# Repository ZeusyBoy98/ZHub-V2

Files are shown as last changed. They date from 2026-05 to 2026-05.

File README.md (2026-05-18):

# ZHub-V2
A complex USB 3.2 Hub to suite my needs.
Made for Hack Club Fallout

## Zine
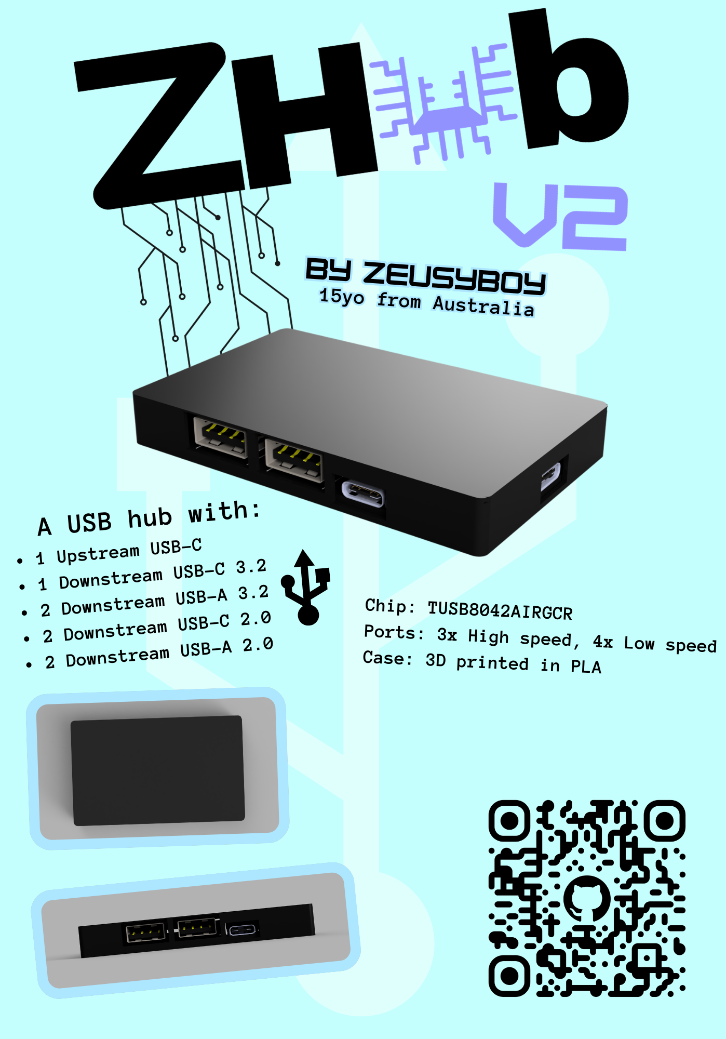
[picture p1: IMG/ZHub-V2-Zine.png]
Zine


## What?
A basic USB hub with:
<ul>
<li> 1 Upstream USB-C
<li> 1 Downstream USB-C 3.2
<li> 2 Downstream USB-A 3.2
<li> 2 Downstream USB-C 2.0
<li> 2 Downstream USB-A 2.0
<li> USB 2.0 because I used a very basic chip
</ul>

## Why?
Because I don't have any USB-C USB hubs and A to C adapters are annoying. If I can just have one good USB hub on me at all times, that can allow me to plug all the stuff I could possibly need in, then that achieves my goal.

## How?
In order to make this project for yourself, you'll need to purchase the board and get it assembled through PCBA with all the components below (PCB manufacturer-acceptable BOM at PCB/Gerbers/bom.csv). You'll also have to 3D print the case.
| Quantity | Item | URL | Unit Price ($USD) | Total Price ($USD) |
| --- | --- | --- | --- | --- |
| 5 | CoreChips SL2.1A | https://www.lcsc.com/product-detail/C192893.html  | 0.2522 | 1.26 |
| 10 | USB A 2.0 Receptacle | https://www.lcsc.com/product-detail/C668591.html  | 0.0667 | 0.67 |
| 20 | USB C 2.0 Receptacle | https://www.lcsc.com/product-detail/C2765186.html | 0.0666 | 1.33 |
| 100 | 1uf Capacitor | https://www.lcsc.com/product-detail/C107372.html  | 0.0019 | 0.19 |
| 100 | 100nf Capacitor | https://www.lcsc.com/product-detail/C309458.html  | 0.0012 | 0.12 |
| 100 | 5.1k Resistor | https://www.lcsc.com/product-detail/C2906874.html | 0.0006 | 0.06 |
| 5 | TUSB8042A | https://www.lcsc.com/product-detail/C2860610.html | 8.1684 | 40.84 |
| 10 | USB A 3.1 Receptacle | https://www.lcsc.com/product-detail/C309458.html  | 0.23 | 2.3 |
| 5 | USB C 3.2 Receptacle | https://www.lcsc.com/product-detail/C134092.html  | 1.0565 | 5.28 |
| 20 | ESD Diode | https://www.lcsc.com/product-detail/C82044.html | 0.0359 | 0.72 |
| 10 | 24Mhz Crystal | https://www.lcsc.com/product-detail/C5444545.html | 0.0615 | 0.62 |
| 10 | Polyfuse | https://www.lcsc.com/product-detail/C883135.html  | 0.0616 | 0.62 |
| 10 | 22uf Capacitor | https://www.lcsc.com/product-detail/C105226.html  | 0.0455 | 0.46 |
| 100 | 18pf Capacitor | https://www.lcsc.com/product-detail/C106202.html  | 0.0012 | 0.12 |
| 100 | 10uf Capacitor | https://www.lcsc.com/product-detail/C315248.html  | 0.0092 | 0.92 |
| 10 | 9.53k Resistor | https://www.lcsc.com/product-detail/C6127312.html | 0.0682 | 0.68 |
| 100 | 4.7k Resistor | https://www.lcsc.com/product-detail/C105871.html  | 0.0008 | 0.08 |
| 100 | 43k Resistor | https://www.lcsc.com/product-detail/C185415.html  | 0.001 | 0.10 |
| 100 | 1M Resistor | https://www.lcsc.com/product-detail/C138033.html  | 0.0009 | 0.09 |
| 5 | 220@100MHz Ferrite Bead | https://www.lcsc.com/product-detail/C454099.html  | 0.151 | 0.76 |
| 5 | 3.3V Buck Converter | https://www.lcsc.com/product-detail/C780769.html  | 0.4705 | 2.35 |
| PCB | | | 5.2 | 5.2 |
| PCBA | | | 145.82 | 145.82 |
| Shipping | | | | 10.51 |
| Total | | | | 161.53 |

### Build Guide:

#### 1. Preparation<br>
Before starting, make sure you have:
<ul>
<li>The gerbers, pick and place file, and BOM, all available in this repository at (PCB/production)
<li>A 3D printer (or get the printed parts from someone else)
</ul>

#### 2. Ordering
Go to your PCB manufacturer of choice (Make sure they have PCBA) and follow their instructions on how to order.

#### 3. Case
3D print the print file, CAD/ZHub-V2-Print.3mf <br>
This has all the case parts you need (top and bottom)

#### 4. Assembly
Once the case has finished printing, place the assembled PCB into said case, then get the lid and slide it into the grooves of the bottom half of the case to close it.

#### 5. Profit
Plug a USB-C to C cable into the upstream port of the hub (the one not next to any other ports), and plug the other end of that cable into your computer. Then plug whatever USB devices into the downstream ports and...

This project does not need firmware, so you're good to go!

Enjoy your ZHub!!!

## Renders
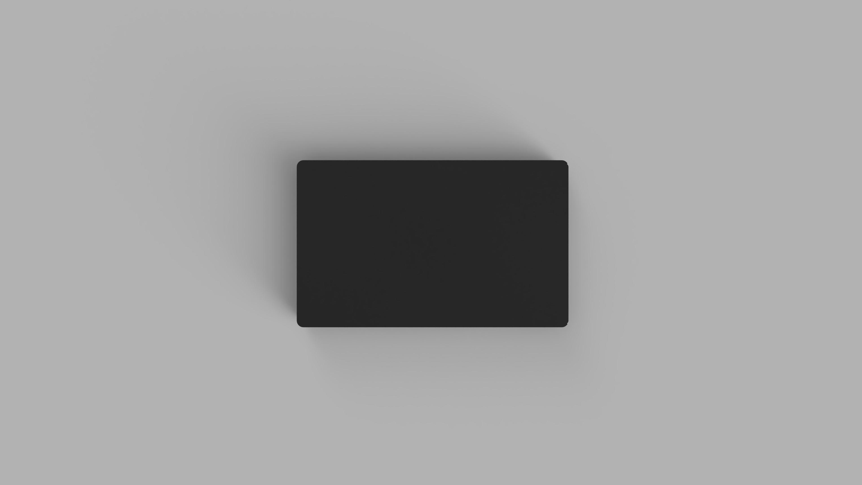
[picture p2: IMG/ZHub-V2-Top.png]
Top

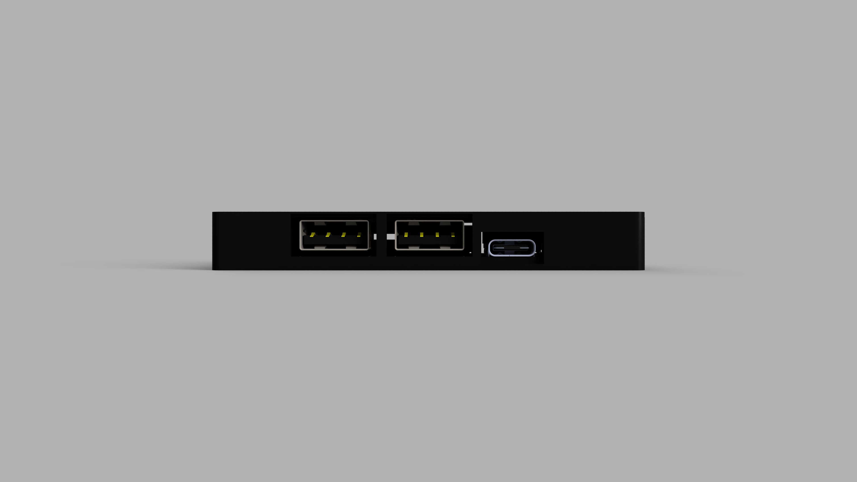
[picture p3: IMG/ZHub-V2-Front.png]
Front

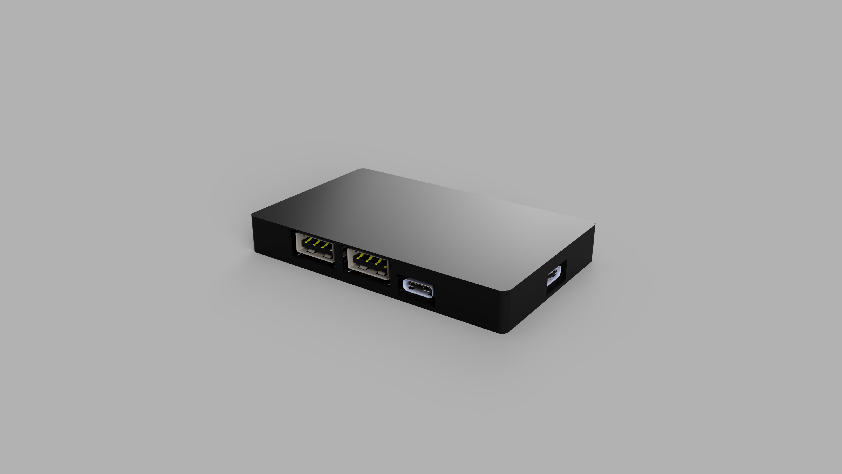
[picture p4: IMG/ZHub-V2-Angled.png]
Angled


## Designing
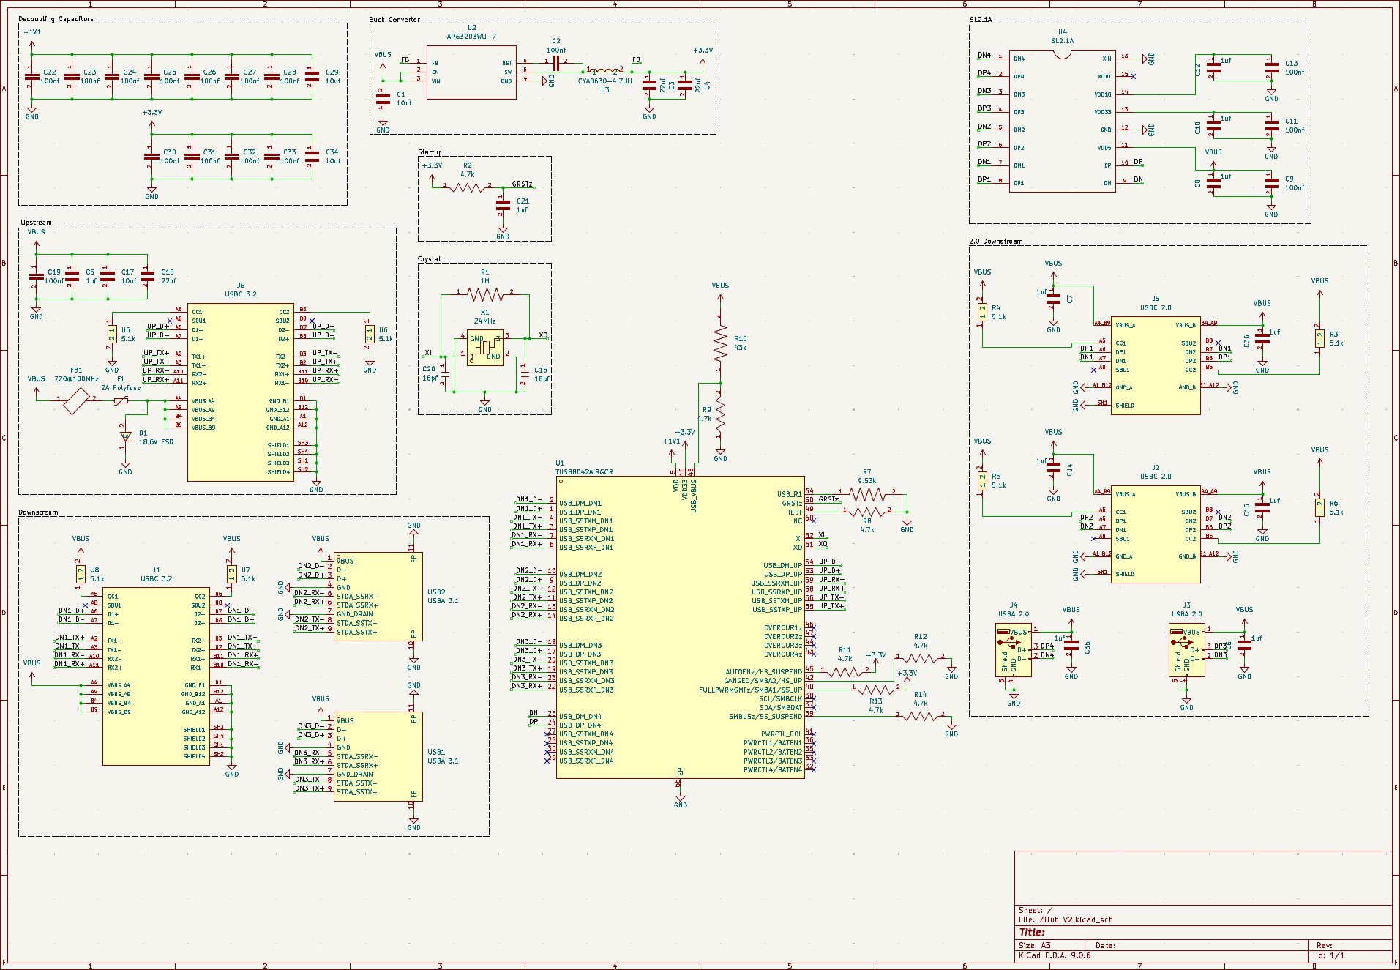
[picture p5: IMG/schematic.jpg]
Schematic

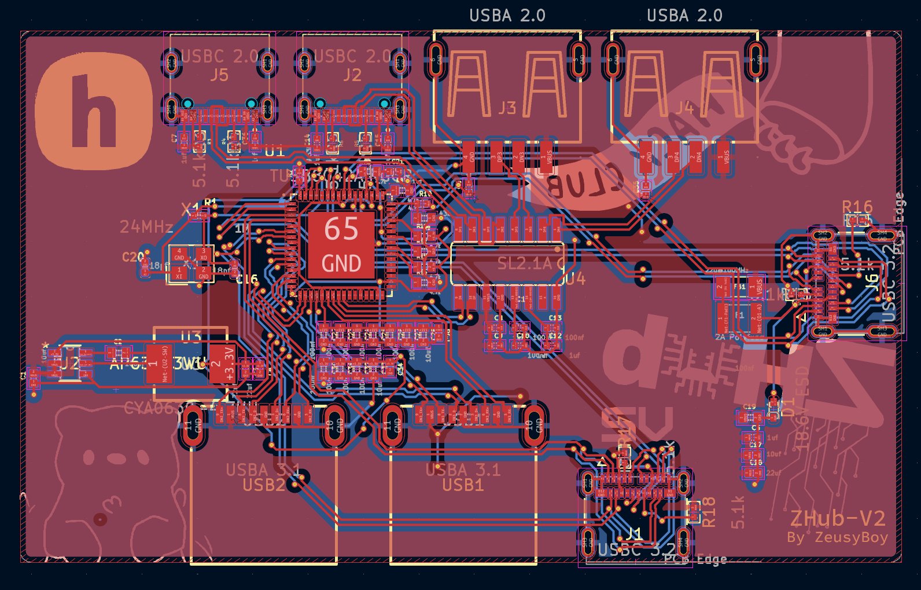
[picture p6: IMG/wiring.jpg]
Wiring

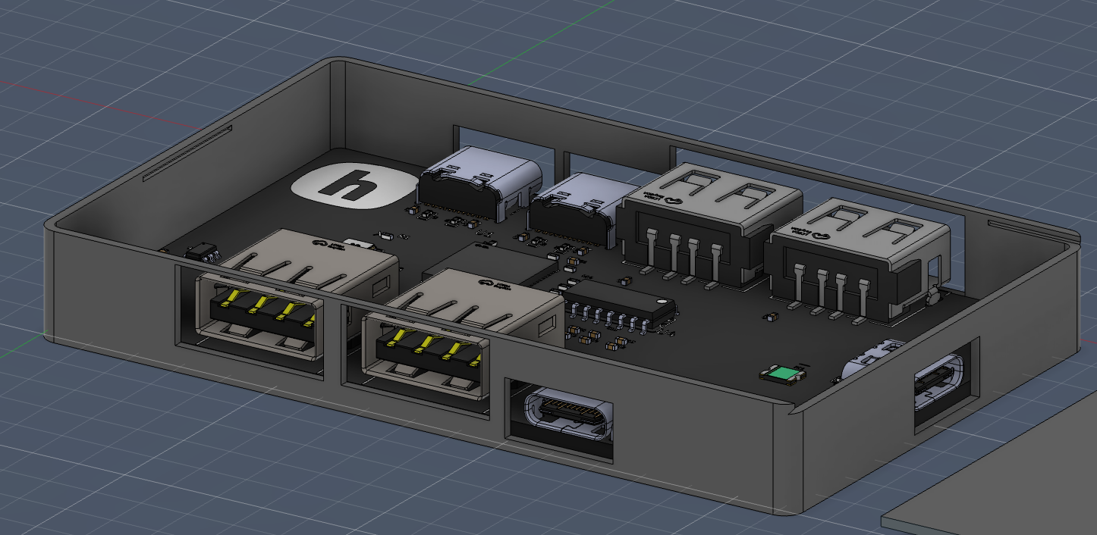
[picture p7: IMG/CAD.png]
CAD


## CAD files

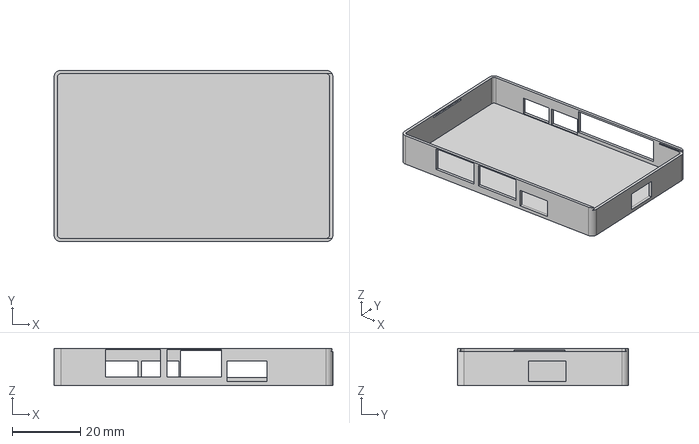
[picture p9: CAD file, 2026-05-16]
CAD/Parts/ZHub-V2-Bottom.stp
82.0 x 50.4 x 11.0 mm

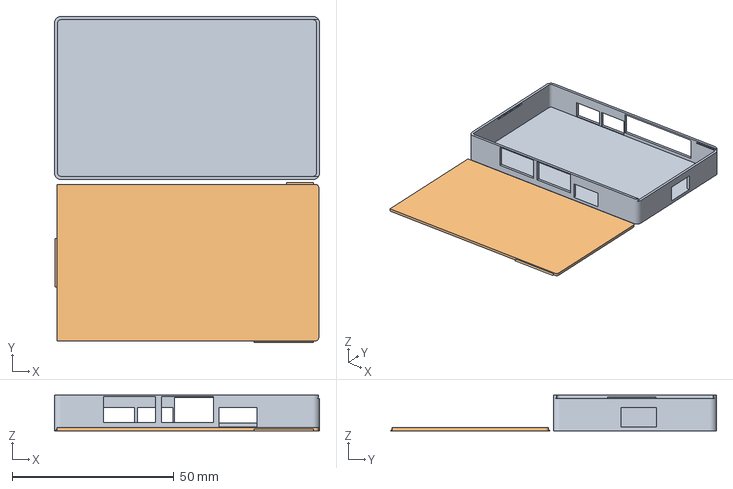
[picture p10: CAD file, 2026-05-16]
CAD/ZHub-V2-Print.3mf
82.0 x 100.8 x 11.0 mm
ZHub-V2-Bottom.stp
ZHub-V2-Top.stp

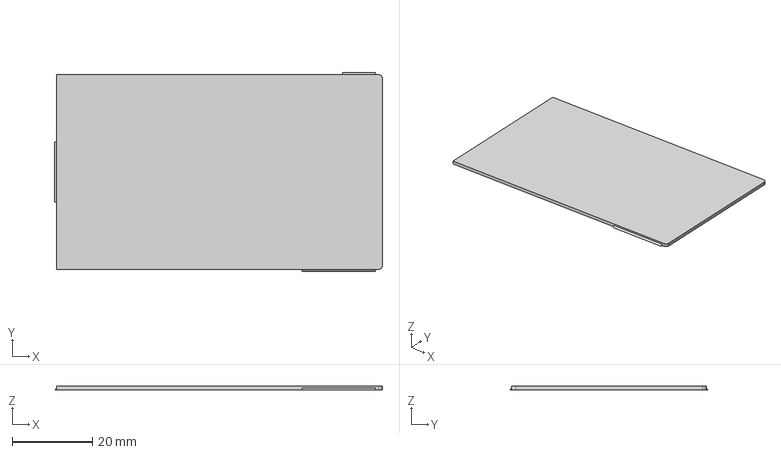
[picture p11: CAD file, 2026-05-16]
CAD/Parts/ZHub-V2-Top.stp
81.5 x 49.4 x 1.00 mm

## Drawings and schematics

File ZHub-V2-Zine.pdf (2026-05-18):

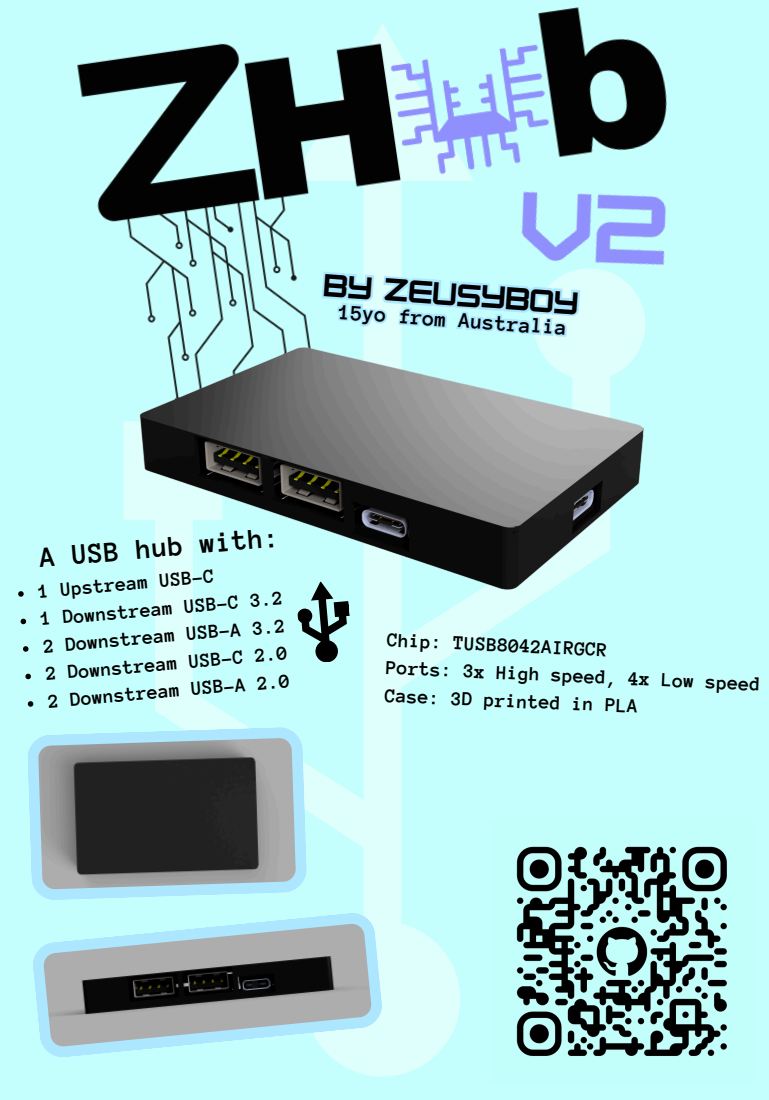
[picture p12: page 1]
1 Upstream USB-C 1 Downstream USB-C 3.2 2 Downstream USB-A 3.2 2 Downstream USB-C 2.0 2 Downstream USB-A 2.0; 15yo from Australia 1; usyBoy; Chip: TUSB8042AIRGCR

By ZeusyBoy By ZeusyBoy B

om Australia 15yo from Australia

A USB hub with:

Ports: 3x High speed, 4x Low speed

Case: 3D printed in PLA

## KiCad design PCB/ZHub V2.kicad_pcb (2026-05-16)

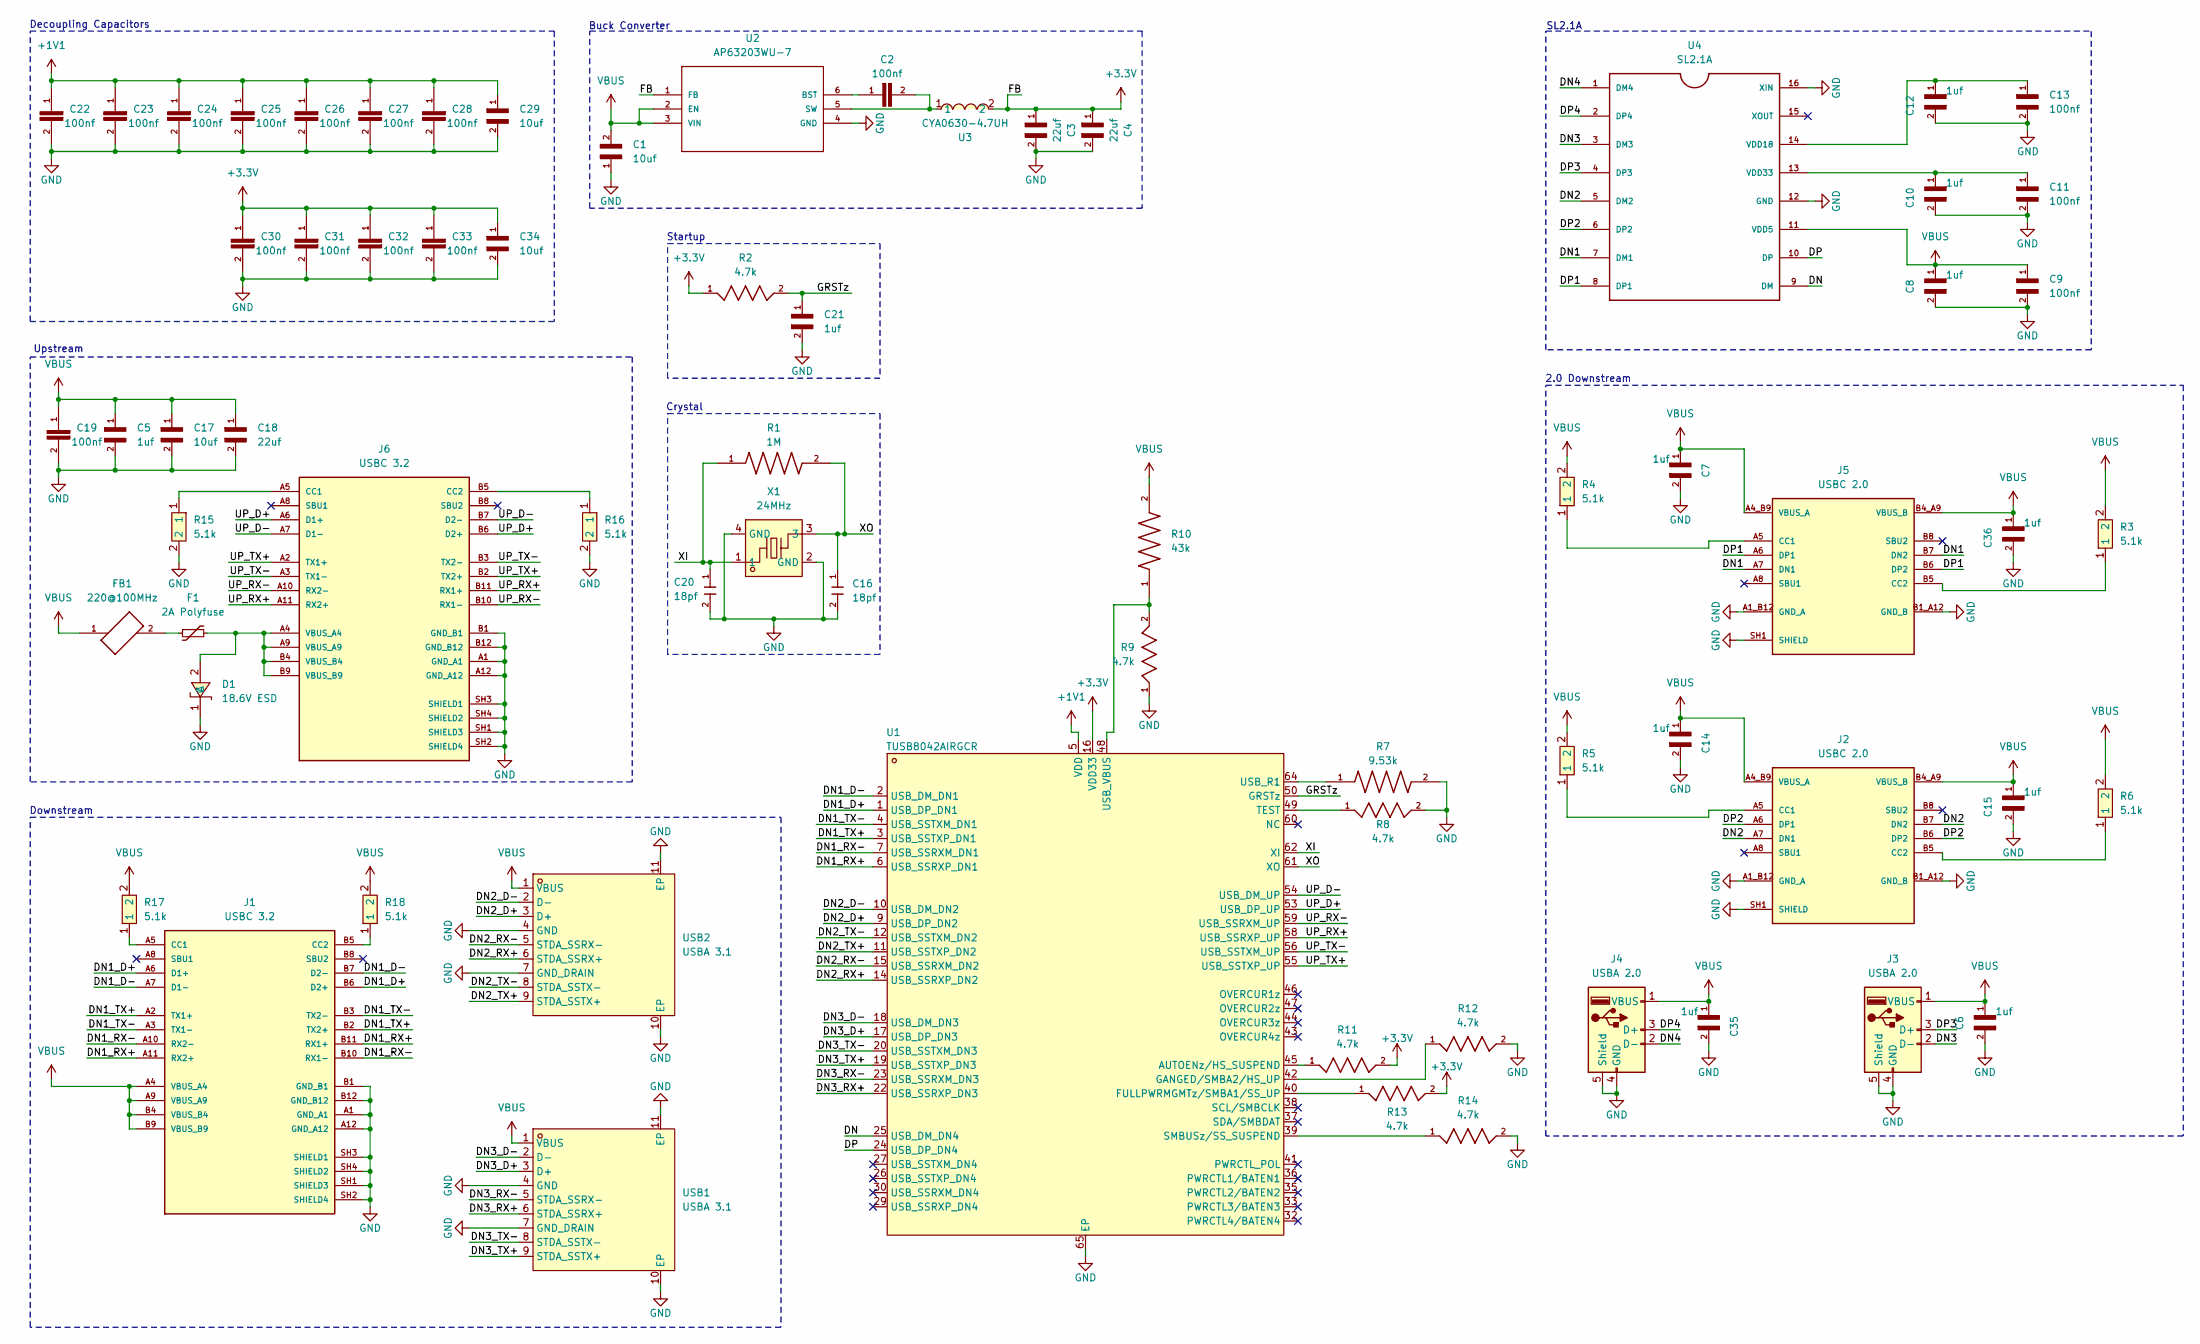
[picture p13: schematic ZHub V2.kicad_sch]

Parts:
C1, C17, C29, C34: 10uf; 10uf_10V_0402
C2, C19, C22, C23, C24, C25, C26, C27, C28, C30, C31, C32, C33: 100nf; 100nf_10V_0402
C3, C4, C18: 22uf; 22uf_6.3V_0402
C5, C21: 1uf; 1uf_6.3V_0402
C6, C7, C8, C10, C12, C14, C15, C35, C36: 1uf; 1uf_0402
C9, C11, C13: 100nf; 100nf_0402; DigiKey_Part_Number 399-C1210V104KCRACTUCT-ND
C16, C20: 18pf; 18pf_15V_0402; MPN CC0402JRNPO9BN180
D1: 18.6V ESD; SOD-523F_L1.2-W0.8-LS1.7-RD; LCSC Part C82044
F1: 2A Polyfuse; 1210
FB1: 220@100MHz; 220_100MHz_bead
J1, J6: USBC 3.2; MOLEX_3.2_TYPEC; PARTREV A7
J2, J5: USBC 2.0; SHOUHAN_TYPE-C_16PIN_2MD__073_; PARTREV A
J3, J4: USBA 2.0; USB-A-TH_10.0QHHTZB6.3
R1: 1M; 1M_50V_0402; PARTREV Nov-2024
R2, R8, R9, R11, R12, R13, R14: 4.7k; 4.7k_50V_0402
R3, R4, R5, R6: 5.1k; R0402; PARTREV 3/1/2020; LCSC Part C2906874
R7: 9.53k; 9.53k_0402; PARTREV V6
R10: 43k; 43k_50V_0402; DigiKey_Part_Number 311-43.0KLRCT-ND
R15, R16, R17, R18: 5.1k; R0402; LCSC Part C2906874
U1: TUSB8042AIRGCR; VQFN-64_L9.0-W9.0-P0.50-TL-EP6.0; LCSC Part C2860610
U2: AP63203WU-7; 3.3V_buck; MPN AP63203WU-7
U3: CYA0630-4.7UH; 5A_4.7uH_Inductor; LCSC Part C5189748
U4: SL2.1A; SLA2.1s
USB1, USB2: USBA 3.1; USB-A-SMD_U-A-39WD-W-1; LCSC Part C3020886
X1: 24MHz; CRYSTAL-SMD_4P-L3.2-W2.5-BL; LCSC Part C5444545

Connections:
+1V1: C22.1, C23.1, C24.1, C25.1, C26.1, C27.1, C28.1, C29.1, U1.5 (VDD), U1.8 (VDD), U1.13 (VDD), U1.21 (VDD), U1.28 (VDD), U1.31 (VDD), U1.51 (VDD), U1.57 (VDD)
+3.3V: C3.1, C4.1, C30.1, C31.1, C32.1, C33.1, C34.1, R2.1, R11.2, R13.2, U1.16 (VDD33), U1.34 (VDD33), U1.52 (VDD33), U1.63 (VDD33), U2.1 (FB), U3.2
/DN: U1.25 (USB_DM_DN4), U4.9 (DM)
/DN1: J5.A7 (DN1), J5.B7 (DN2), U4.7 (DM1)
/DN1_D+: J1.A6 (D1+), J1.B6 (D2+), U1.1 (USB_DP_DN1)
/DN1_D-: J1.A7 (D1-), J1.B7 (D2-), U1.2 (USB_DM_DN1)
/DN1_RX+: J1.A11 (RX2+), J1.B11 (RX1+), U1.6 (USB_SSRXP_DN1)
/DN1_RX-: J1.A10 (RX2-), J1.B10 (RX1-), U1.7 (USB_SSRXM_DN1)
/DN1_TX+: J1.A2 (TX1+), J1.B2 (TX2+), U1.3 (USB_SSTXP_DN1)
/DN1_TX-: J1.A3 (TX1-), J1.B3 (TX2-), U1.4 (USB_SSTXM_DN1)
/DN2: J2.A7 (DN1), J2.B7 (DN2), U4.5 (DM2)
/DN2_D+: U1.9 (USB_DP_DN2), USB2.3 (D+)
/DN2_D-: U1.10 (USB_DM_DN2), USB2.2 (D-)
/DN2_RX+: U1.14 (USB_SSRXP_DN2), USB2.6 (STDA_SSRX+)
/DN2_RX-: U1.15 (USB_SSRXM_DN2), USB2.5 (STDA_SSRX-)
/DN2_TX+: U1.11 (USB_SSTXP_DN2), USB2.9 (STDA_SSTX+)
/DN2_TX-: U1.12 (USB_SSTXM_DN2), USB2.8 (STDA_SSTX-)
/DN3: J3.2 (D-), U4.3 (DM3)
/DN3_D+: U1.17 (USB_DP_DN3), USB1.3 (D+)
/DN3_D-: U1.18 (USB_DM_DN3), USB1.2 (D-)
/DN3_RX+: U1.22 (USB_SSRXP_DN3), USB1.6 (STDA_SSRX+)
/DN3_RX-: U1.23 (USB_SSRXM_DN3), USB1.5 (STDA_SSRX-)
/DN3_TX+: U1.19 (USB_SSTXP_DN3), USB1.9 (STDA_SSTX+)
/DN3_TX-: U1.20 (USB_SSTXM_DN3), USB1.8 (STDA_SSTX-)
/DN4: J4.2 (D-), U4.1 (DM4)
/DP: U1.24 (USB_DP_DN4), U4.10 (DP)
/DP1: J5.A6 (DP1), J5.B6 (DP2), U4.8 (DP1)
/DP2: J2.A6 (DP1), J2.B6 (DP2), U4.6 (DP2)
/DP3: J3.3 (D+), U4.4 (DP3)
/DP4: J4.3 (D+), U4.2 (DP4)
/GRSTz: C21.1, R2.2, U1.50 (GRSTz)
/UP_D+: J6.A6 (D1+), J6.B6 (D2+), U1.53 (USB_DP_UP)
/UP_D-: J6.A7 (D1-), J6.B7 (D2-), U1.54 (USB_DM_UP)
/UP_RX+: J6.A11 (RX2+), J6.B11 (RX1+), U1.58 (USB_SSRXP_UP)
/UP_RX-: J6.A10 (RX2-), J6.B10 (RX1-), U1.59 (USB_SSRXM_UP)
/UP_TX+: J6.A2 (TX1+), J6.B2 (TX2+), U1.55 (USB_SSTXP_UP)
/UP_TX-: J6.A3 (TX1-), J6.B3 (TX2-), U1.56 (USB_SSTXM_UP)
/XI: C20.1, R1.1, U1.62 (XI), X1.1
/XO: C16.1, R1.2, U1.61 (XO), X1.3
GND: C1.1, C3.2, C4.2, C5.2, C6.2, C7.2, C8.2, C9.2, C10.2, C11.2, C12.2, C13.2, C14.2, C15.2, C16.2, C17.2, C18.2, C19.2, C20.2, C21.2, C22.2, C23.2, C24.2, C25.2, C26.2, C27.2, C28.2, C29.2, C30.2, C31.2, C32.2, C33.2, C34.2, C35.2, C36.2, D1.1 (C), J1.A1 (GND_A1), J1.A12 (GND_A12), J1.B1 (GND_B1), J1.B12 (GND_B12), J1.SH1 (SHIELD3), J1.SH2 (SHIELD4), J1.SH3 (SHIELD1), J1.SH4 (SHIELD2), J2.A1_B12 (GND_A), J2.B1_A12 (GND_B), J2.SH1 (SHIELD), J2.SH2 (SHIELD), J2.SH3 (SHIELD), J2.SH4 (SHIELD), J3.4 (GND), J3.5 (Shield), J3.6, J4.4 (GND), J4.5 (Shield), J4.6, J5.A1_B12 (GND_A), J5.B1_A12 (GND_B), J5.SH1 (SHIELD), J5.SH2 (SHIELD), J5.SH3 (SHIELD), J5.SH4 (SHIELD), J6.A1 (GND_A1), J6.A12 (GND_A12), J6.B1 (GND_B1), J6.B12 (GND_B12), J6.SH1 (SHIELD3), J6.SH2 (SHIELD4), J6.SH3 (SHIELD1), J6.SH4 (SHIELD2), R7.2, R8.2, R9.1, R12.2, R14.2, R15.2, R16.2, U1.65 (EP), U2.4 (GND), U4.12 (GND), U4.16 (XIN), USB1.4 (GND), USB1.7 (GND_DRAIN), USB1.10 (EP), USB1.11 (EP), USB2.4 (GND), USB2.7 (GND_DRAIN), USB2.10 (EP), USB2.11 (EP), X1.2 (GND), X1.4 (GND)
unnamed: D1.2 (A), F1.2, J6.A4 (VBUS_A4), J6.A9 (VBUS_A9), J6.B4 (VBUS_B4), J6.B9 (VBUS_B9)
unnamed: F1.1, FB1.2
unnamed: J1.A5 (CC1), R17.1
unnamed: J1.B5 (CC2), R18.1
unnamed: J2.A5 (CC1), R5.1
unnamed: J2.B5 (CC2), R6.1
unnamed: J5.A5 (CC1), R4.1
unnamed: J5.B5 (CC2), R3.1
unnamed: J6.A5 (CC1), R15.1
unnamed: J6.B5 (CC2), R16.1
unnamed: R11.1, U1.45 (AUTOENz/HS_SUSPEND)
unnamed: R13.1, U1.40 (FULLPWRMGMTz/SMBA1/SS_UP)
unnamed: R12.1, U1.42 (GANGED/SMBA2/HS_UP)
unnamed: R14.1, U1.39 (SMBUSz/SS_SUSPEND)
unnamed: R8.1, U1.49 (TEST)
unnamed: R7.1, U1.64 (USB_R1)
unnamed: R9.2, R10.1, U1.48 (USB_VBUS)
unnamed: C2.1, U2.6 (BST)
unnamed: C2.2, U2.5 (SW), U3.1
unnamed: C12.1, C13.1, U4.14 (VDD18)
unnamed: C10.1, C11.1, U4.13 (VDD33)
VBUS: C1.2, C5.1, C6.1, C7.1, C8.1, C9.1, C14.1, C15.1, C17.1, C18.1, C19.1, C35.1, C36.1, FB1.1, J1.A4 (VBUS_A4), J1.A9 (VBUS_A9), J1.B4 (VBUS_B4), J1.B9 (VBUS_B9), J2.A4_B9 (VBUS_A), J2.B4_A9 (VBUS_B), J3.1 (VBUS), J4.1 (VBUS), J5.A4_B9 (VBUS_A), J5.B4_A9 (VBUS_B), R3.2, R4.2, R5.2, R6.2, R10.2, R17.2, R18.2, U2.2 (EN), U2.3 (VIN), U4.11 (VDD5), USB1.1 (VBUS), USB2.1 (VBUS)

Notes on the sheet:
2.0 Downstream
Startup
Buck Converter
Downstream
Upstream
SL2.1A
Crystal
Decoupling Capacitors

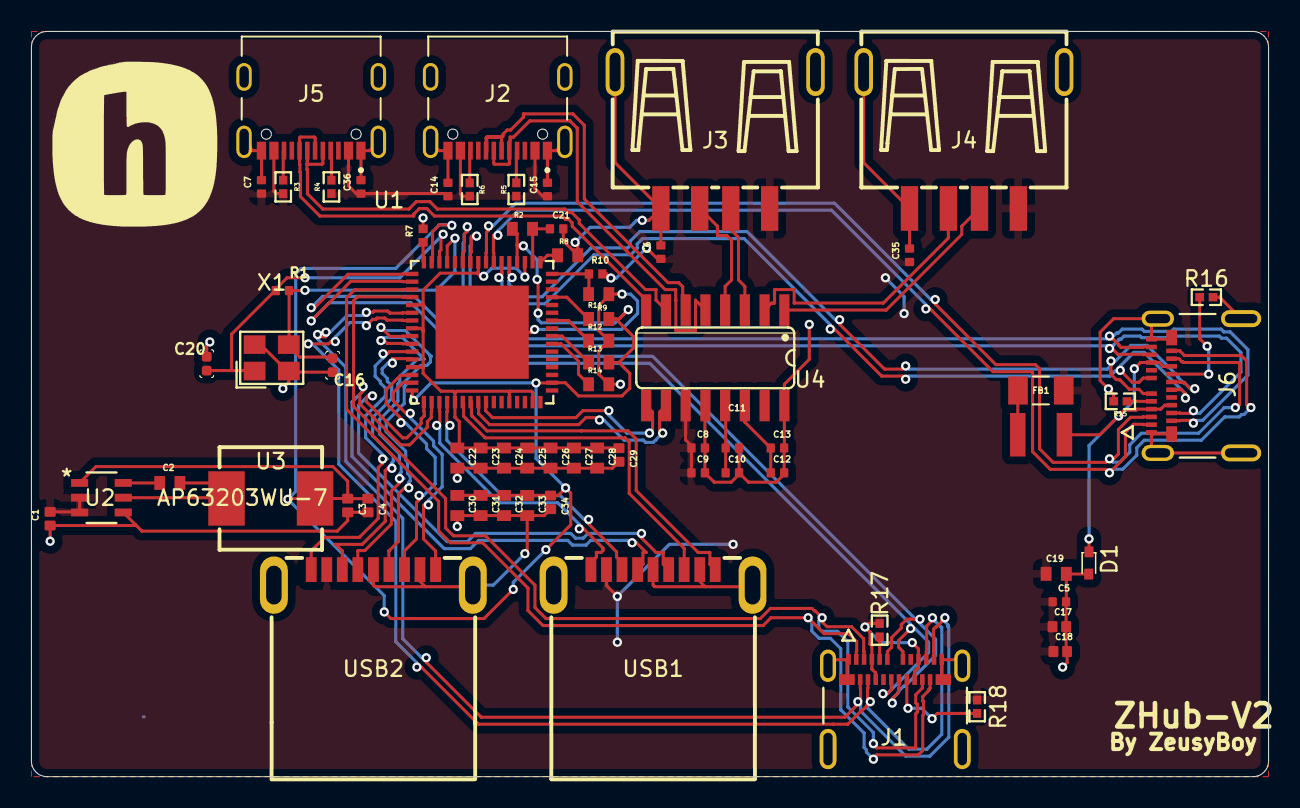
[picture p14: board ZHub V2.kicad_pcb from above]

Board: 2 copper layers, 79.6 x 48.0 mm, 70 parts (0 on the bottom side), 62 nets.

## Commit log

2026-05-10 Finish schematic, PCB, and BOM
    [BOM.csv, ZHub V2.kicad_pcb, ZHub V2.kicad_sch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]
2026-05-16 Finish case
    [ZHub V2.kicad_pcb, ZHub-V2-Bottom.stp, ZHub-V2-Print.3mf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]
